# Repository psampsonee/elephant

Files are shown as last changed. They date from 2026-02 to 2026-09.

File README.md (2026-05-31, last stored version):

# Elephant

This project is intended to be a low-power audio player for a stuffed animal. The goal is to make a box that goes into a stuffed animal that takes up minimal space and lasts as long as possible on a single battery. The box should make an animal noise when its shaken, but only after some time has elapsed since the last time it has made a noise. The noise should be audible in a quiet room and should be immediately recognizable as a particular animal - in this case, an elephant. When the box has just been shaken, it will count - with very little power - a certain amount of time, then after that, wait to be shaken. Then, if you don't shake it, it should sit there, sipping very little power. When you do, it should make the animal noise within some amount of time (maybe a few fractions of a second).

## Power Budget / Battery Life

The board will have three main power states, corresponding to the three states of the state machine:

- Low-power
    - In this state, the STM32 is in standby mode. Everything but the backup domain - that is, the RTC and the backup registers - is powered off. Due to the quiescent currents of various devices during this state, it is expected that a little under 1 uA of current will draw from the main batteries.
- Buck Converter Off
    - The STM32 backup domain is powered only from its VBAT pin by the CR-2032 coin cell. Only the RTC and the backup registers are powered. This allows the STM32 to retain an accurate representation of the time. This will draw up to 2 uA from the CR-2032. However, testing will need to be done to verify this current consumption with the RTC in its particular configuration.
    - In this state, the buck converter becomes the predominate power sink for the main batteries, drawing 1 uA of current while shut down.
- Play Sound (highest power)
    - The microcontroller and DAC/amplifier (SSM2518) are both active, and the SSM2518 draws most of the current. This state will last for a few seconds, but contributes to a significant amount of the energy consumption of the main batteries. The LT-8640 will be supplying roughly 3.7W in this state and drawing 0.41A from the battery.

## State Machine

This firmware uses the Gang-of-Four State pattern: Elephant is the Context and each concrete state implements enter/toggle/exit. Each state is exposed via a singleton instance (no per-state heap allocations); any per-device data lives in the Elephant object. Interrupt service routines are kept tiny — they set flags or enqueue events — and the main loop/state handlers process those events and perform transitions, ensuring deterministic, non-blocking behavior. See notes in the README about concurrency (brief critical sections) and buffer sizing (samples vs bytes) (TODO).

The states in the state machine will correspond to each of the states mentioned in the **Power Budget / Battery Life** section above, with the following transition causes and tasks:

- Light Sleep
    - Upon waking up from standby, the firmware will detect why was reset (confirm entering standby), and why it woke (confirm RTC alarm) in main(). Once the STM32 is in this state, the STM32 will be in standby mode, corresponding to the "Low-power" power state.
    - Transitions to Deep Sleep when real time clock alarm fires. When the alarm fires, the STM32 briefly powers on completely to do the transition. During this transition, the microcontroller must save any data that needs to be retained (probably: last sound played (avoid repetition) and any state information needing to be retained) to spare backup registers, then pull the *GPIO_pwr_buck_off* pin low, triggering the 74AUP1G74 to clear, tying the LT8640 EN/UV pin low and causing it to power down.
- Deep Sleep
    - This state never sees a transition to another state in the code as the STM32 is completely powered off during it. Instead, the transition from this state occurs when the STM32 powers back on due to the LT8640 restoring power to the board. Corresponds to **Buck Converter Off**
    - "Transitions" to Play Sound when the tilt switch pulls the preload pin of the 74AUP1G74 low briefly, pulling Q high and turning the LT8640 back on.
- Play Sound
    - Upon powering on, the firmware will detect why was reset (POR), and why it woke (power restored) in main().  In this state, the STM32 will prepare the EEPROM for reading, then load data from the EEPROM in packets while playing a sound through the Audio object. Corresponds to the power state of the same name.
    - Transitions to Light Sleep when the Audio object completes playing a sound. During this transition, the STM32 sets an alarm 4 hours ahead of the current time to trigger it to wake up and transition into deep sleep.

## Choice of Components

### LT8640 Buck Converter

The LT8640 was chosen due to its high efficiency and ability to be turned off via the enable pin, which takes very little current to drive and allows the battery to be **practically** disconnected from the circuit (x nA is expected to leak while the LT8640 is turned off).

### STM32F401CCU Microcontroller

- Powerful enough to play intelligible audio
- Low-power options allow for RTC battery backup and external wakeups
- Nearly the same chip as on a "Black Pill" (For development)

### M95M04 EEPROM

- 4 Mbit is enough for several audio files (show calcs)
- Low Power
- 200 year data retention - not an SD card

### SSM2518 I2S DAC and amplifier

- Low quiescent current
- A one-chip solution to audio (maybe I dont need to say this in the final readme)
- Powerful enough to be heard at 2W per channel
-Very low noise

### LM66100 ideal diodes (power source OR-ing)

- Low quiescent (0.3uA) and leakage (max 600nA at operating temperature) currents
- Actively controlled PFET limits reverse-current to nanoamps. This is especially important for the coin cell to avoid damage, especially in high-temperature environments where a BAT54 could cause a failure in low-power mode.
- LM66100 ideal diodes were selected for power-source OR-ing due to their low quiescent current and low reverse leakage; reverse-current behavior into the coin cell is still being validated in simulation.

## Next Steps

## Risks and Unknowns

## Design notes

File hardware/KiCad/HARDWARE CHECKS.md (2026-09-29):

# Hardware Checks for Evaluation Board
## Schematic Checks
### 1. Power
- [x] Values of LT8640 passives match simulated LTSpice values.
- [ ] Power OR network topology verified against reference schematic
- [ ] Power OR network values verified via simulation or calculations
- [ ] Power OR back-current impedance to coin cell deemed acceptable
- [ ] Power OR decoupling caps are acceptable values
- [ ] Test points identified and verified
- [ ] 0-ohm bridges identified and verified
- [x] Inductor saturation - provide documented calculations verifying value.
- [x] Capacitor voltage and DC bias deratings keep capacitance values within specification
- [ ] Resistors are rated for anticipated peak and steady state currents based on LTSpice
- [ ] Regulator is capable of supplying expected steady state current without going into shutdown.
- [ ] Power network simulated against several conditions:
    - [x] Startup
    - [x] Steady State
    - [ ] Source-transition
    - [ ] Shutdown
- [ ] peak current and RMS current extracted from simulation and checked against component ratings as relevent
- [ ] Worst-case node voltages checked against component absolute-maximum ratings
- [ ] Thermal checks for devices
    Gather steady state (playback) and peak power + duration, and/or integrated energy
    - [ ] LT8640
    - [ ] LM66100 (x2)
    - [ ] Resistors
    compare against whatever thermal limits/guidance the datasheet actually provides
    flag anything that needs layout-dependent thermal verification
    require ~20% margin where a meaningful numeric limit exists

### 2. Tilt Switch Circuit
- [ ] Topology verified against test circuit
- [ ] Values verified against test circuit
- [ ] Test points identified and verified
- [ ] 0-ohm bridges identified and verified

### 3. MCU
- [ ] Topology verified against datasheet and/or known-good circuit
- [ ] VCAP1 value verified from datasheet
- [ ] LSE crystal impedance, capacitance, frequency verified against calcs from datasheet
- [ ] LSE network capacitor values verified against calcs from datasheet
- [ ] LSE crystal startup/load-cap tolerances
- [ ] HSE crystal frequency is an acceptable value for audio playback
- [ ] HSE crystal impedance, capacitance verified against calcs from datasheet
- [ ] HSE network capacitor values verified against calcs from datasheet
- [ ] HSE crystal startup/load-cap tolerances
- [ ] Has proximal AND distal decoupling caps at acceptable values
- [ ] Test points identified and verified
- [ ] 0-ohm bridges identified and verified
- [ ] NRST circuit
- [ ] Check NRST minimum pulse / pull-up / capacitor against datasheet recommendations
- [ ] BOOT pin state - defaults to allowing normal boot, but resettable.
- [ ] SWD pins
- [ ] VDDA/VSSA (analog circuit) - capacitors and reliability
- [ ] All VDD/VSS pins have connections
- [ ] Pin assignments (and functions) match a possible configuration in CubeMX
- [ ] Pin assignments are not absurd for board layout
    - [ ] Keep pins going to the same place close together
    - [ ] Decide beforehand where neighbors will be in relation to MCU and sanity-check pin locations for interconnections
- [ ] Verify every required power up sequencing requirement from datasheet
- [ ] Verify a recovery method exists if firmware disables/reconfigures SWD (i.e. reset or BOOT)
- [ ] Check that any peripherals will be successfully driven given I/O current limits.

### 4. EEPROM
- [ ] Pin functions backchecked against datasheet
- [ ] Pin connections backchecked against datasheet
- [ ] Has proximal AND distal decoupling caps at acceptable values
- [ ] Test points identified and verified
- [ ] 0-ohm bridges identified and verified
- [ ] **Default** states of pins do not:
    - [ ] Erase or change data
    - [ ] Put the EEPROM in an undefined state
    - [ ] Damage the EEPROM
    - [ ] Make the EEPROM consume unnecessary power
- [ ] Chosen EEPROM works with 3.3V SPI signals
- [ ] Maximum clock speed of the EEPROM exceeds intended STM32 SPI clock speed
- [ ] Check write-protect behavior during brownout/power collapse during writes when attached to debugger.
- [ ] Confirm SPI timing including CS setup/hold, not merely max SCK.

### 5. Audio Out
- [ ] Topology verified against datasheet and/or known-good circuit
- [ ] Pin functions backchecked against datasheet
- [ ] Pin connections backchecked against datasheet
- [ ] Checked capacitor values against available engineering calculations
- [ ] Has proximal AND distal decoupling caps at acceptable values
- [ ] Test points identified and verified
- [ ] 0-ohm bridges identified and verified
- [ ] Config pin reset states
- [ ] Address pin reset states
- [ ] Control pin reset states
- [ ] I2S logic levels 0V and 3.3V
- [ ] allowed MCLK/BCLK/LRCLK relationships versus what STM32 can actually generate
- [ ] speaker impedance/power against amplifier operating conditions
- [ ] output topology requires no accidental ground-referenced probing
- [ ] Output capacitor / filter requirements per datasheet
- [ ] Output network matches datasheet recommendation for short speaker leads
- [ ] Check maximum instantaneous supply current with intended speaker power
- [ ] Verify I2S word length / frame format can be supplied by STM32
- [ ] Check amplifier input and control pin states when MCU reset/unpowered conditions that can actually occur.

### 6. Debug Interface
- [ ] UART lines are all present
- [ ] UART lines have correct topology
- [ ] SWD lines are all present
- [ ] SWD lines have correct topology

### 7. Interface Checks
- [ ] Every IC supply pin checked for:
    - [ ] correct voltage
    - [ ] acceptable voltage range
    - [ ] adequate capacitor voltage rating
- [ ] Absolute-max / signal-level compatibility checked between devices
- [ ] Power-up/default states of important control pins verified
- [ ] MCU boot/reset configuration verified
- [ ] No required pull-ups/pull-downs omitted
- [ ] Connector pinouts independently backchecked
- [ ] Grounds and power-net names checked for accidental separation/connection
- [ ] ERC run and every warning reviewed rather than blindly waived
- [ ] Every external interface has a usable ground reference available for probing
- [ ] Programming/debug connector physically includes everything needed to recover a blank board
- [ ] Confirm no signal depends upon firmware driving it correctly during MCU reset
- [ ] Confirm unused pins are intentionally handled
- [ ] Confirm footprint/package selections against ordering part numbers
- [ ] Every connector is checked for mis-plug or reversed-plug consequences
- [ ] Every test point can be physically probed after assembly 
    (include this in board layout as well; tall components may make this hard)
- [ ] Verify PCB footprints:
    - [ ] Dimensions
    - [ ] Pin 1 orientation
    - [ ] Exposed pads
    - [ ] Courtyard
- [ ] Dead-MCU debug audit: identify every node that would need to be measured or controlled to diagnose a board where the MCU never runs; provide test access as appropriate.

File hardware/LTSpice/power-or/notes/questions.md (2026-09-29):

# Relevant Design Questions
1. What seams exist at source-transition and what are their worst-case conditions?
    A. What is the minimum VBackup voltage during handoff?
2. What are the worst-case leakage currents of the power-or network?
3. What are the worst-case transient and steady-state currents which could contribute to thermal load?
    - Particularly, worst-case capacitor charge inrush current.
4. What are the failure modes for this configuration?
    A. What happens if no coin cell is installed?
    B. Does a decaying buck output produce brownout or chatter?
    C. Any leakage through GPIOs when VDD=0?
    D. What happens when the backup node is shorted?
    E. What happens when the coin cell is reversed?
    F. What happens when the buck converter rail is shorted?
    G. What happens when the coin cell is at end of life?
    H. What does a replaced coin cell transient current look like when backup cap is discharged?
    I. What are the worst-case temperature conditions in regards to reverse leakage and FET behavior (hot AND cold)?
    J. What happens when one or both of the ideal diodes are shorted?
5. What is an acceptable VBackup capacitance?
    A. Start with 1uF and change if needed.
6. What happens during main power startup?
    A. Is voltage overshoot within an acceptable range?
    
# Simulations

- Handoff: Buck -> Coin cell
    - Model coin cell internal resistance
    - Check transient currents and backup cap discharge
    - Check diode states for chatter
    - Check backup voltage for brownout condition - Drives capacitance
- Handoff: Coin cell -> Buck
    - Check for voltage overshoot
    - Check for reverse transient current to coin cell
- Buck power off: reverse leakage to powered-off buck converter rail.
- Steady state, buck on: reverse leakage to coin cell
- Brand new coin cell transient: maximum current
- Failure conditions:
    - Backup battery reverse voltage
    - Backup node short
    - No backup battery
    - 2VDC buck voltage
    - Shorted ideal diode(s)
- Source crossover (Vbuck ~= Vcoin); buck sweeps slowly. Exposes partial diode conduction, source sharing, or chatter.

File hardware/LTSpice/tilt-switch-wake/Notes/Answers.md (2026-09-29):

## Questions

1. With worst-case maximum switch-closure duration, component values and parasitics, how does the RC node charge?
    - RC charging is effectively instantaneous relative to the minimum assumed switch-closure duration.
2. What maximum voltage does the RC node reach under the worst-case closure?

Measurements:
    - Maximum RC and EN node voltages
3. What is the minimum time that the EN node remains above threshold voltage (0.96V) during discharge?
4. How does GPIO interact with the tilt switch circuit?
    - Leakage current during discharge
    - backpowering
5. What is the worst-case leakage current from the tilt switch circuit while the buck converter is off?
    - With the tilt switch open, the always-on 3.3 V source has no intended DC path into the circuit. Remaining current is limited to physical open-switch leakage, expected to be negligible (nA-scale). No further simulation required.

## Simulations

1. Charging - Answers 1 and 2
2. Discharge / hold time - Answers 3

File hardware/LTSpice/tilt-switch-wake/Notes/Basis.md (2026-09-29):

# RC Time Constant Basis

## Experimentally derived variables

### STM32F401CU (Scope)

Minimum MCU supply voltage for GPIO assertion: 1.73V
Minimum time to assert GPIO: 5.69ms

### LT8640A-3.3

Output voltage: 3.3V
Time to reach minimum boot voltage (1.8V): 3.07ms (simulation result)

## Datasheet Variables:

LT8640 EN voltage: 1V
LT8640 EN hysteresis: 40mV

## Assumed / calculated variables

Minimum RC time above EN threshold: (5.69+3.07)*1.2=~10.5ms
Maximum RC charge voltage (90% of 90% of 3.3V): 2.67V
Discharging RC time constant (t1 = 10.5ms, V1 = 0.96V, V0 = 2.67V): -(t1/(ln(V1/V0)))=10.27ms
-> Given C=22nF, R=~600k

## Nominal charging and discharging characteristics

Based on this datasheet:
https://signalquest.com/wp-content/uploads/Tilt-and-Vibration-Sensor-SQ-SEN-200.pdf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

According to the vibration characteristic curve, assuming that either low-to-high or high-to-low counts as a transition, the estimated average closed-contact duration at \(D_{\max}\) is:

{2*D_max/(N_transitions|D_max)} ~= {2*0.65/1100} ~= 1.18ms

Since we don't have a particular switch in mind at this time, and it must be normally open for the wakeup circuit we have in mind to work, we will assume:

1.18 ms is approximately 12× 0.1 ms

and use 0.1ms as the assumed minimum available charging pulse, pending verification with real hardware.

## Crude impulse sensor

To later add functionality to determine roughly how much effort was put into a shake, an NMOS inverter circuit will be used in the final hardware. This will be neglected in LTspice tests.

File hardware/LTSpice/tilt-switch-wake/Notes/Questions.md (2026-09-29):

## Questions

1. With worst-case maximum switch-closure duration, component values and parasitics, how does the RC node charge?
2. What maximum voltage does the RC node reach under the worst-case closure?
Sweeps:
    - N/A
Measurements:
    - Maximum RC and EN node voltages
3. What is the minimum time that the EN node remains above threshold voltage (0.96V) during discharge?
4. How does GPIO interact with the tilt switch circuit?
    - Leakage current during discharge
    - backpowering
5. What is the worst-case leakage current from the tilt switch circuit while the buck converter is off?
    - With the tilt switch open, the always-on 3.3 V source has no intended DC path into the circuit. Remaining current is limited to physical open-switch leakage, expected to be negligible (nA-scale). No further simulation required.

## Simulations

1. Charging - Answers 1 and 2
2. Discharge / hold time - Answers 3

## Answers

1. RC charging is effectively instantaneous relative to the minimum assumed switch-closure duration.
2. 
    A. Maximum RC node voltage: 2.97V
    B. Maximum EN node voltage: 2.86V
3. Minimum time above threshold: 12.0ms
4. Open switch creates no meaningful off-state leakage path.
5. GPIO clamp/backfeed behavior is negligible in the modeled transient.

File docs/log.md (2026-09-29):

## 8/29/2026

Current State:

- Wrote schematic checklist for Rev A board

Next steps:

- Clean up LT-8640 LTSpice model and begin verifying component ratings in the power section, adjusting idealized assumptions.
- Establish one canonical cleaned-up LT-8640 baseline before beginning simulations. Record the source of each value (i.e. datasheet) for future reference.
    - Voltage-derated input/output capacitor values
    - Capacitor ESR, esp. on output cap.
    - Inductor DCR
    - Realistic battery voltage and source resistances
    - One parameterized load (parameterized current source)
- Each question gets a separate simulation file.
    - Startup at worst-case load (verify ~3.3V)
    - Load transient from idle to playback
    - Battery corner: Vbat_min and worst-case source resistances
    - Component stress: Peak/RMS currents and voltages
    - Shutdown: Check behavior when EN drops below 1 V
    - Source / OR behavior: Backfeed/source transitions (multiple tests)
        - Backfeed steady state
        - Transition transients
        
## 9/1/2026

Current State:

- Cleaned up LTSpice directory structure
- Began parameterizing LTSpice buck convertor model

Next Steps:

- Construct effective/test values from nominal values × derating/tolerance factors
- Apply those parameters throughout the LTspice model
- Populate nominal values, tolerances, derating factors, ESR/DCR, etc. from datasheets/design documentation; cite sources in bib.md

9/5/2026

Current State:

- Set up Buck Convertor LTSpice workspace and documentation files.
- Began gathering parameters and SPICE models from datasheets

Next Steps:

- Finish gathering parameters from datasheets, putting documentation in .inc/bib.md/bib.ods as needed
- Prepare test conditions.

9/6/2026

Current State:

- Gathered component parameters and models from vendors with documentation
- Ran initial bringup simulation

Next Steps:

- Sweep Distal Vin/Vout capacitors for anticipated current dips
- Test battery corners
- Test various loads
- Test startup under load
- Test shutdown

9/7/2026

Current State:

- Completed baseline simulation
- Produced C_IN_DISTAL sizing simulation during steady state
- For steady state, a capacitance of 47uF captures most of the improvement in VIN ripple and VIN minimum, with diminishing returns above that.

Next Steps:

- C_IN_DISTAL startup simulation and tests
- Battery corner tests.

9/12/2026

Current State

Re-defined test conditions - input bulk capacitor
Determined component measurements
Ran all three conditions and revised the above two based on results

Next Steps

Revise steady state power for 30% rather than 20% max playback power
Write load switching measurements in LTSpice

9/13/2026

All VIN-cap tests rerun with consistent battery states and recovery metrics. Next: tabulate results only—do not change tests unless the table exposes a problem.

9/19/2026

Current State

Verified VIN bulk capacitor and VOUT bulk capacitor selection.

Next Steps

Buck converter design verification checkoffs from existing checklist
Power-or circuit simulation:
    - Design criteria
    - Test questions
    - Corners / state transitions
    
9/20/2026

Current State

Checked Buck KiCad against LTSpice: topology and nominal values.
Added evaluation features to KiCad schematic.
Organized LTSpice folders.

Next Steps

Verify buck enable behavior.
    - Disable threshold, falling EN
    - Enable thresh, rising EN
    - Shutdown decay (Time from 3.3V to 1.8V) when EN pulled low quickly. Should be around (60uC per amp)s.
Investigate passive wake circuit with MCU self-hold.
    - determine required EN hold time from the results above
    - measure/estimate MCU boot-to-GPIO-assert time
    - see whether RC + diode can guarantee that at worst-case VBackup
    - check standby leakage
Power-or verifications

9/21/2026

Results:
- Time to decay when disabled: 863us.
- Time to reach minimum boot voltage (1.8V): 3.07ms

Next steps

Investigate passive wake circuit with MCU self-hold and nominal EN voltage thresholds.

9/22/2026

Current State
- Captured time from 1.73V (experimentally verified minimum GPIO voltage) applied to input rail to GPIO assert on STM32F401 in gpio-assert-test.
- Result:5.69ms
- Negligible observed run-to-run variation over several trials.
- Target time for RC filter to remain above 0.96V (LT8640 EN threshold): (5.69ms+0.00307ms)*1.2=~6.84ms (20% safety factor)

Next steps:
- Determine RC time constant to meet the requirement of decaying from 2.67V to 0.96V in 6.84ms
- Determine minimum viable tilt switch closed time (Let's say the RC must charge to at least 90% of 2.97V (which is 90% of 3.3V))
- Simulate using the selected impulse and RC values (as well as parasitics/nonideals) to verify.

9/26/2026

Current State
- Plans for impulse sensing via NMOS inverter
- Wrote up RC basis
- Simulated to verify answers to tilt switch circuit questions
    - EN hold time: 9.19 ms minimum vs. 6.84 ms required
    - RC charging effectively instantaneous relative to 100 µs assumed switch pulse
    - No meaningful GPIO backfeed/leakage observed

Next steps
- Pick parts
- Power OR ckt

9/27/2026

Current State
- Copied tilt switch wake circuit into KiCad
- Determined that a series resistor to the RC node of the wake circuit would suffice for switch sensing.
- Designed questions and tests for power-or circuit

Next Steps
- Perform Power-Or tests
- Complete power checklist
- Move on to MCU checks
- there was a magnitude error in the RC calculation. Fix it.

9/29/2026

Current State
- Recalculated RC values, updated docs.
- Re-simulated tilt switch circuit with datasheet component values, found that chosen parts exceed the new requirements.
- Produced baseline power-or simulation with old LM66100 model

Next steps
- Create and execute power handoff tests
- Create and execute source crossover test
- Create and execute reverse leakage tests (buck off/buck on)
- Create and execute Cbackup sweep test (variant of buck->coin cell test)
- Create and execute the four fault conditions highlighted (backup node short/diodes shorted/coin cell flipped/no coin cell)
- Complete power checklist

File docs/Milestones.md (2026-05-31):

Milestones

Initial Prototype
- Play sound
- Read/write EEPROM
- Play sound while using EEPROM
- RTC alarms are implemented
- State machine works properly
- Sleep/Shutdown implemented and the prototype works functionally
- Prototype performs full cycle:
    sleep → wake → play → sleep
- startup and pin assertion time recorded (See next section)

Power (SPICE)
- Buck converter implemented, known working (as designed on schematic)
- Power OR working
- tilt switch/EN trigger working (~100ms enabled after tilt event, verified during prototyping)

Firmware (It largely exists, but big chunks dont or need to be rewritten)
Firmware architecture reviewed
Critical modules reviewed (state machine, audio, EEPROM)
Wake source correctly identified after reset
Unit tests implemented
Unit tests passing

Board readiness
Schematic reviewed
Power paths verified
Buck converter layout reviewed
Decoupling verified
Test points/0-ohm ties identified and added
Instrumentation points added (current measurement):
    shunt resistor or test pads for current
    buck enable signal probe
    VBAT probe
ERC/DRC

Bring-up
Board powers up, no overheating
3.3V rail stable
MCU programmable
Amplifier powers up, works
Audio playback verified

Verification
(board approaches simulation results for power consumption)
Low-power current measured
Buck-off current measured
Playing current measured and adjusted to balance audibility and battery life
Wake latency measured

Reliability
Several shake events tested
Sleep/wake cycles tested
failure modes tested: one battery or the other removed, tilt switch stuck, one thing or another won't turn on or off
Go to university and see if i can get time on a thermal camera, verify nothing heats more than necessary
Long-duration idle test (24–72 hours)

Most likely to stall: 
Playing a sound
Wake / power-gating logic
Board power-up

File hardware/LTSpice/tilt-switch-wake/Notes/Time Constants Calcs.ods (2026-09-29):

 | R | C | Tau | Initial Voltage | t1 | V|t1 | Threshold voltage | Time-to-threshold
Charging (Nom) | 10 | 2.20E-08 | 0.00000022 | 2.97 | 1.00E-04 | 2.97 | 1.04 | 9.48292289775191E-08
Discharging (Nom) | 5.00E+05 | 2.20E-08 | 0.011 | 2.97 | 1.05E-02 | 1.14216500573209 | 0.96 | 0.0124232234206835
Charging (Worst Case) | 10 | 0.0000000242 | 0.000000242 | 2.31 | 1.00E-04 | 2.31 | 1.04 | 1.44771811023295E-07
Discharging (Worst Case)

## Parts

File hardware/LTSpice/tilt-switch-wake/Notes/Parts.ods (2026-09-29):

Reference | LTSpice Param | Description | Manufacturer | Part No. | Source | Parameters Used | Notes
 |  | Charging Capacitor | YAGEO | CC0805KRX7R7BB223 | https://yageogroup.com/download/specsheet/CC0805KRX7R7BB223 | DC Bias (3.3% at ~3V), Tolerance
 |  | Discharge Resistor | YAGEO | RC0805FR-07590KL | https://yageogroup.com/content/datasheet/asset/file/PYU-RC_GROUP_51_ROHS_L | Resistance, Power
 |  | Diodes | SMC | BAT54 | https://www.smc-diodes.com/propdf/BAT54(A)(C)(S)%20N0123%20REV.D.pdf | LTSpice Model for part number
 |  | GPIO Series Resistor | YAGEO | RC0603FR-0710KL | https://yageogroup.com/content/datasheet/asset/file/PYU-RC_GROUP_51_ROHS_L | N/A

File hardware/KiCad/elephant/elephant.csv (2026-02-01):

# | Reference | Qty | Value | Footprint | DNP
1 | BT1 | 1 | 9v Battery | Connector_JST:JST_PH_B2B-PH-K_1x02_P2.00mm_Vertical
2 | BT2 | 1 | Coin Cell | Battery:BatteryHolder_Keystone_1057_1x2032
3 | C1, C2, C4, C14 | 4 | 1uF | Capacitor_SMD:C_0603_1608Metric
4 | C3 | 1 | 100u | Library:Capacitor SMD 2917 (7343 Metric)
5 | C5, C6, C7, C11 | 4 | 470pF | Capacitor_SMD:C_0603_1608Metric
6 | C8, C9 | 2 | 2pF | Capacitor_SMD:C_0603_1608Metric
7 | C10 | 1 | 4.7uF,<1Ω | Capacitor_SMD:C_0603_1608Metric
8 | C12, C13 | 2 | 4pF | Capacitor_SMD:C_0603_1608Metric
9 | C15 | 1 | 10nF | Capacitor_SMD:C_0603_1608Metric
10 | C16, C18 | 2 | 100nF | Capacitor_SMD:C_0603_1608Metric
11 | C17 | 1 | 4.7uF | Capacitor_SMD:C_0603_1608Metric
12 | D3 | 1 | LED | LED_SMD:LED_0603_1608Metric
13 | FB1, FB2, FB3, FB4 | 4 | FerriteBead_Small | Inductor_SMD:L_0402_1005Metric
14 | H1, H2, H3, H4 | 4 | MountingHole | MountingHole:MountingHole_2.7mm_M2.5
15 | J1 | 1 | Conn_01x04_Pin | Connector_JST:JST_PH_B4B-PH-K_1x04_P2.00mm_Vertical
16 | J2 | 1 | Conn_01x05_Pin | Connector_JST:JST_PH_B5B-PH-K_1x05_P2.00mm_Vertical
17 | L1 | 1 | 2.2uH | Inductor_SMD:L_Bourns-SRN8040_8x8.15mm
18 | LS1, LS2 | 2 | Speaker | Connector_JST:JST_PH_B2B-PH-K_1x02_P2.00mm_Vertical
19 | R1 | 1 | 10k | Resistor_SMD:R_0603_1608Metric
20 | R2 | 1 | 500Ω | paul:TC42 – 2 mm SMD Trimpot - Bournes
21 | R4 | 1 | 2.4kΩ | Resistor_SMD:R_0603_1608Metric
22 | R7 | 1 | 330 Ω | Resistor_SMD:R_0603_1608Metric
23 | R8 | 1 | 17.8k | Resistor_SMD:R_0603_1608Metric
24 | SW1 | 1 | SW_TILT | Connector_PinHeader_2.54mm:PinHeader_1x02_P2.54mm_Vertical
25 | TP1 | 1 | 3v3 | TestPoint:TestPoint_Pad_D1.0mm
26 | TP2 | 1 | GND | TestPoint:TestPoint_Pad_D1.0mm
27 | U1 | 1 | LT8640 | paul:LT8640
28 | U3 | 1 | SSM2518 | Package_DFN_QFN:QFN-20-1EP_4x4mm_P0.5mm_EP2.5x2.5mm
29 | U4 | 1 | M95M04 | Package_SO:TSSOP-8_4.4x3mm_P0.65mm
30 | U5 | 1 | STM32F401CCUx | Package_DFN_QFN:QFN-48-1EP_7x7mm_P0.5mm_EP5.6x5.6mm
31 | Y1 | 1 | 32.768kHz, 6pF, 50kΩ | Crystal:Crystal_SMD_Abracon_ABS25-4Pin_8.0x3.8mm
32 | Y2 | 1 | 16MHz, 7pF, 60Ω | Crystal:Crystal_SMD_3225-4Pin_3.2x2.5mm

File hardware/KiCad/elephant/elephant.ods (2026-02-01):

# | Reference | Qty | Value | Footprint | Digikey Part
1 | BT1 | 1 | 9v Battery | Connector_JST:JST_PH_B2B-PH-K_1x02_P2.00mm_Vertical | https://www.digikey.com/en/products/detail/keystone-electronics/232/303804
2 | BT2 | 1 | Coin Cell | Battery:BatteryHolder_Keystone_1057_1x2032 | https://www.digikey.com/en/products/detail/keystone-electronics/1057TR/4692903
3 | C1, C2, C4, C14 | 4 | 1uF | Capacitor_SMD:C_0603_1608Metric | https://www.digikey.com/en/products/detail/samsung-electro-mechanics/CL10A105KA8NNNC/3886760
4 | C3 | 1 | 100u | Library:Capacitor SMD 2917 (7343 Metric) | https://www.digikey.com/en/products/detail/kyocera-avx/TCJY107M016R0050/5001463
5 | C5, C6, C7, C11 | 4 | 470pF | Capacitor_SMD:C_0201_0603Metric | https://www.digikey.com/en/products/detail/murata-electronics/GRM033R71C471KA01D/2543516
6 | C8, C9 | 2 | 2pF | Capacitor_SMD:C_0201_0603Metric | https://www.digikey.com/en/products/detail/murata-electronics/GRM0335C1H2R0BA01D/4358709
7 | C10 | 1 | 4.7uF,<1Ω | paul:1411 (3528 Metric) | https://www.digikey.com/en/products/detail/vishay-sprague/TR3B475K035C0700/2259924
8 | C12, C13 | 2 | 4pF | Capacitor_SMD:C_0201_0603Metric | https://www.digikey.com/en/products/detail/murata-electronics/GRM0335C1E4R0CA01D/4358231
9 | C15 | 1 | 10nF | Capacitor_SMD:C_0201_0603Metric | https://www.digikey.com/en/products/detail/murata-electronics/GRM033R71A103KA01D/702460
10 | C16, C18 | 2 | 100nF | Capacitor_SMD:C_0201_0603Metric | https://www.digikey.com/en/products/detail/murata-electronics/GRM033R61A104ME15D/2175191
11 | C17 | 1 | 4.7uF | Capacitor_SMD:C_0603_1608Metric | https://www.digikey.com/en/products/detail/samsung-electro-mechanics/CL10A475KP8NNNC/3886702
12 | D3 | 1 | LED | LED_SMD:LED_0603_1608Metric | https://www.digikey.com/en/products/detail/creeled-inc/XQEGRN-H2-0000-000000B01/5423124
13 | FB1, FB2, FB3, FB4 | 4 | FerriteBead_Small | Inductor_SMD:L_0402_1005Metric | https://www.digikey.com/en/products/detail/laird-signal-integrity-products/MI0402K121R-10/4765745
14 | H1, H2, H3, H4 | 4 | MountingHole | MountingHole:MountingHole_2.7mm_M2.5 | N/A
15 | J1 | 1 | Conn_01x04_Pin | Connector_JST:JST_PH_B4B-PH-K_1x04_P2.00mm_Vertical | N/A
16 | J2 | 1 | Conn_01x05_Pin | Connector_JST:JST_PH_B5B-PH-K_1x05_P2.00mm_Vertical | N/A
17 | L1 | 1 | 2.2uH | Inductor_SMD:L_Bourns-SRN8040_8x8.15mm | https://www.digikey.com/en/products/detail/bourns-inc/SRN8040-2R2Y/2756130
18 | LS1, LS2 | 2 | Speaker | Connector_JST:JST_PH_B2B-PH-K_1x02_P2.00mm_Vertical | https://www.digikey.com/en/products/detail/pui-audio-inc/AS04008CO-WR-R/1745536
19 | R1 | 1 | 10k | Resistor_SMD:R_0603_1608Metric | https://www.digikey.com/en/products/detail/yageo/RC0603FR-0710KL/726880
20 | R2 | 1 | 500Ω | paul:TC42 – 2 mm SMD Trimpot - Bournes | https://www.digikey.com/en/products/detail/bourns-inc/TC42X-2-501E/3722204
21 | R4 | 1 | 2.4kΩ | Resistor_SMD:R_0603_1608Metric | https://www.digikey.com/en/products/detail/yageo/RC0603FR-072K4L/727023
22 | R7 | 1 | 330 Ω | Resistor_SMD:R_0603_1608Metric | https://www.digikey.com/en/products/detail/yageo/RC0603JR-07330RL/726769
23 | R8 | 1 | 17.8k | Resistor_SMD:R_0603_1608Metric | https://www.digikey.com/en/products/detail/yageo/RC0603FR-0717K8L/726983
24 | SW1 | 1 | SW_TILT | Connector_PinHeader_2.54mm:PinHeader_1x02_P2.54mm_Vertical | N/A
25 | TP1 | 1 | 3v3 | TestPoint:TestPoint_Pad_D1.0mm | N/A
26 | TP2 | 1 | GND | TestPoint:TestPoint_Pad_D1.0mm | N/A
27 | U1 | 1 | LT8640 | paul:LT8640 | https://www.digikey.com/en/products/detail/analog-devices-inc/LT8640AJUDCM-3-3-PBF/17952220
28 | U3 | 1 | SSM2518 | Package_DFN_QFN:QFN-20-1EP_4x4mm_P0.5mm_EP2.5x2.5mm | https://www.digikey.com/en/products/detail/analog-devices-inc/SSM2518CPZ-R7/3043350
29 | U4 | 1 | M95M04 | Package_SO:TSSOP-8_4.4x3mm_P0.65mm | https://www.digikey.com/en/products/detail/stmicroelectronics/M95M04-DRDW6TP/11482497
30 | U5 | 1 | STM32F401CCUx | Package_DFN_QFN:QFN-48-1EP_7x7mm_P0.5mm_EP5.6x5.6mm | https://www.digikey.com/en/products/detail/stmicroelectronics/STM32F401CCU6/4755971
31 | Y1 | 1 | 32.768kHz, 6pF, 50kΩ | Crystal:Crystal_SMD_Abracon_ABS25-4Pin_8.0x3.8mm | https://www.digikey.com/en/products/detail/ecs-inc/ECS-327-6-17X-C-TR/5875555
32 | Y2 | 1 | 16MHz, 7pF, 60Ω | Crystal:Crystal_SMD_3225-4Pin_3.2x2.5mm | https://www.digikey.com/en/products/detail/ecs-inc/ECS-160-7-33B2-CKM-TR3/18108759

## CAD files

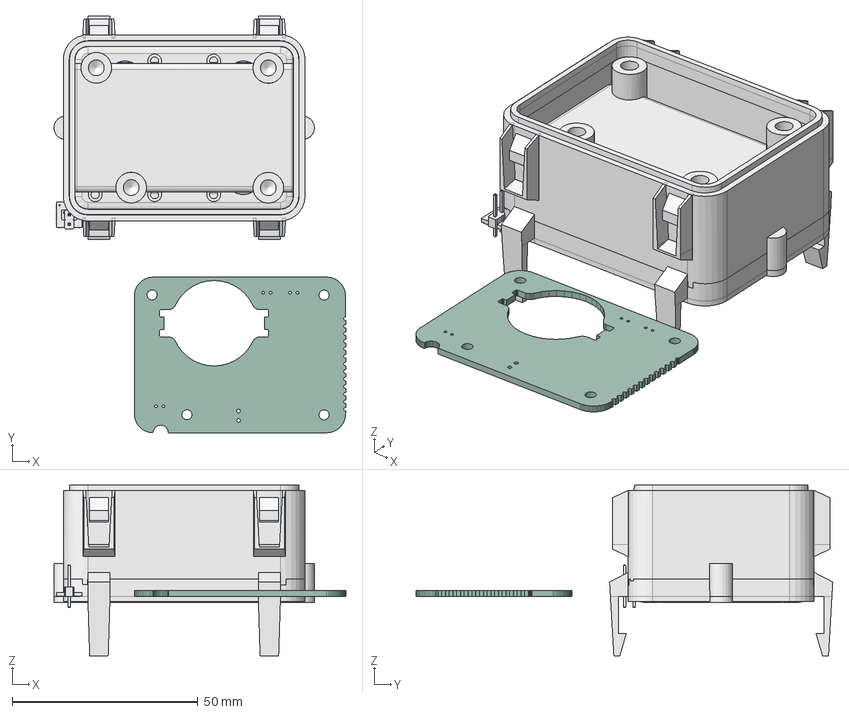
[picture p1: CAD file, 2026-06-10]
hardware/FreeCad/Enclosure.FCStd
78.6 x 112.2 x 46.0 mm
batterydoor
C_0201_0603Metric
C_0201_0603Metric002
C_0201_0603Metric004
QFN-20-1EP_4x4mm_Pitch0.5mm
L_0402_1005Metric
C_0603_1608Metric
L_0402_1005Metric002
C_0603_1608Metric002
C_0201_0603Metric006
PinHeader_1x02_P254mm_Vertical
R_0603_1608Metric
C_0603_1608Metric004
TSSOP_8_44x3mm_P065mm
C_0201_0603Metric008
Crystal_SMD_3225-4Pin_3.2x2.5mm
QFN_48_1EP_7x7mm_P05mm_EP56x56mm
C_0201_0603Metric010
C_0201_0603Metric012
C_0201_0603Metric014
C_0201_0603Metric016
LED_0603_1608Metric
R_0603_1608Metric002
R_0603_1608Metric004
C_0603_1608Metric006
R_0603_1608Metric006
C_0201_0603Metric018
C_0201_0603Metric020
L_0402_1005Metric004
C_0603_1608Metric008
L_0402_1005Metric006

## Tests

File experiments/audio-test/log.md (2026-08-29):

6/27/2026

Current state:
- Narrative/invariants are still confusing.
- SampleSpooler is basically unit-testable and mostly settled.
- AudioPlayer needs a clearer state machine boundary.

Next step:
- Write the smallest AudioPlayer unit test for start(): valid start request moves Idle -> Prepare or Error on invalid arguments.

6/29/2026

Next step:
Turn SampleSpooler functions into booleans for error handling
Write code for AudioPlayer servicePrepare & servicePlayback
Rewrite markRefilled to automatically fill partial buffers with silence

7/3/2026

Current state:
- Added a silence-filling feature for partial buffers in spooler
- Fake sink and storage devices are unit tested and work
- Began adding basic behavior code to servicePrepare()
- Added refillOneBuffer to AudioPlayer.
- Added samplesRemaining_ to AudioPlayer as a way to track samples read from the storage device.

Next steps:
- Make refillOneBuffer functional by adding code to derive samplesRemainingToRead_
- Make one unit test to test refillOneBuffer.
- Make unit tests to test AudioPlayer state machine.

7/4/2026

Current state:
- Fake sink extended to include initialization steps
- AudioPlayer::refillOneBuffer(uint8_t index) defined and written
- Added samplesRemainingToRead_ to track the number of samples to read left from storage for the given clip.
- AudioPlayer servicePrepare code outline written
- Began creating a test harness for the AudioPlayer

Next steps:
- Begin initialization tests for AudioPlayer

7/5/2026

Current state:
- AudioPlayer test code compiles without error
- Basic AudioPlayer initialization tests run without error
- Created test handles struct to easily initialize fake sink, fake storage, and AudioPlayer.

Next steps:
- Write tests for playback state
- Write tests for error states
- Fill in code for servicePlayback

7/7/2026

Current state:
- Wrote servicePlayback code

Next steps:
- Write tests for playback state
- Write tests for error states

7/8/2026

Current state:
- Listed several successful-path unit tests to write in test_audio_player.cpp

Next steps:
- Write successful-path unit tests and get them to pass
- List failure unit tests

7/9/2026

Current state:
- Wrote and successfully ran several happy-path unit tests in test_audio_player.cpp:
    - test_start_while_playing_stops_current_playback_first()
    - test_start_from_finished_enters_prepare_without_stopping()
    - test_service_playback_consumes_samples()
    - test_samples_played_equals_samples_written()
    - test_successful_playback_enters_finished()
    
Next steps:
- Practical and underrun unit tests
- Error-path tests
- Begin tests on real hardware

7/12/2026

Current state:
- Wrote unit test showing that storage sectors are written to the spooler successfully.

Next steps:
- Error-path tests
- Begin tests on real hardware

7/13/2026

Current state:
- Added player read error test and functionality
- Added storage read status functionality
- Added player underrun test (which fails)

Next steps:
- Get the underrun test to pass.

7/14/2026

Current state:
- Wired amplifier on breadboard
- Configured STM32 for 25MHz clock
- Set up TIM4 for 200kHz PWM
- Confirmed 200kHz square wave with USB scope

Next steps:
- Make underrun test pass—trace expected transition and identify where the fake readiness behavior diverges.
- solder pins to speaker
- generate 500Hz sine wave table at 44.1kHz sample rate
- Use a timer interrupt at 44.1 kHz to update TIM4 CCR to the next sine wave sample (+- 10).

7/15/2026

Current State:
- AudioPlayer happy path, error handling, and underrun behavior are tested and work in fake environment.

Next Steps:
- solder pins to speaker
- generate 500Hz sine wave table at 44.1kHz sample rate
- Use a timer interrupt at 44.1 kHz to update TIM4 CCR to the next sine wave sample (+- 10).

7/16/2026

Current state:
- Made a working LM386 amplifier circuit on a breadboard.
- Used STM32 PWM and timers to play a sine wave on the amplifier
- The cat screwed it up.

Next steps:
- Fix the circuit and make it play sound again
- Write PwmAudioSink to interface the PWM audio with the AudioPlayer
- Use hal_callbacks.cpp in App/Src folder to hold a callback for the timer interrupt which updates the PWM sample.

7/17/2026

Current state:
- Created hal_callbacks.cpp to handle all interrupt callbacks that the program may have
- Filled out pwm_audio_sink.h sufficiently to begin implementation
- Created empty function implementations in pwm_audio_sink.cpp

Next steps:
- Implement prepare, start, and interrupt / sample functionality.
- Mind error handling and return false when invariants are violated.

7/20/2026

Current State:
- PwmAudioSink is functional enough to create arbitrary waveforms with expected distortion.
- Tested on Analog Discovery 2.

Next steps:
- Implement PwmAudioSink interrupt failure detection (i.e. timeout / watchdog)
- Reduce amplifier gain with a pot.
- Complete sd_card storage_device implementation
- Test sd_card storage_device implementation
- Test AudioPlayer with SDcard -> PwmAudioSink pipeline in place

7/25/2026

Current State:
- Created 48000 Hz Signed 16-bit PCM test file with Audacity.
- Tested AudioPlayer functionality with SD card storage and PWM audio sink.
- Spotted shadowed variable in AudioSink (isSampleNeeded_).
- AudioPlayer can successfully play an audio clip from storage on a functioning audio sink.

Next Steps:
- Design SSM2518 / EEPROM interface board.
- Configure and verify the SSM2518 over I2C.
- Produce a simple I2S tone.
- Stream a PCM buffer through I2S DMA.
- Connect that sink to the existing AudioPlayer.
- Implement ADPCM compression to optimize for limited EEPROM capacity.

~7/31/2026

Current State:
- Wrote ADPCM codec

Next Steps:
- Testing and integration of ADPCM codec.

8/8/2026

Current State:
- Successfully tested ADPCM codec on PC
- Wrote headers for SampleSource, StorageSampleSource, and PCM/ADPCM sources to convert data into samples
- Refactored AudioPlayer to use SampleSource instead of StorageDevice.
    - Consistently use size_t instead of uint32_t for variable indexes / counts
    - Refactored refillOneBuffer per the SampleSource contract
- Put some code from audio_player.cpp into PCMSampleSource (bookkeeping & some code from refillOneBuffer)

Next Steps:
- Write PCMSampleSource implementation
- Test PCMSampleSource implementation

8/13/2026

Current State:
- Wrote PCMSampleSource.
- Need to assert invariants after the fact

Next Steps:
- Write down PCMSampleSource invariants (esp. getSamples)
- Test PCMSampleSource

8/24/2026

Current State:
- PCMSampleSource is tested
- In process of tesing AudioPlayer with new source_ interface

Next Steps:
- The first sector of storage is being read twice, once by source_.start and once by source_.getSamples. It seems to be a bookkeeping problem at start but I have not traced it through yet.
- Underruns are not being tracked by AudioPlayer at this time.
- Create helper function in the source to handle storage read transactions.

8/24/2026 (B)

Current State:
- Created a dedicated function fillWorkspace() to handle storage read transactions in PCMSampleSource.
- Narrowed underrun problem to a hypothesis: sourceReadPosition_final is invalid.
- Leaving for a week.

Next Steps:
- Test hypothesis
- Make that variable valid.
- Create dedicated tests:
    - Show that blocks are not repeated under normal conditions
    - Show that the contents of each sample out matches the value of the expected sample in.

8/26/2026

Current State:

- Fixed underrun bug: buffers are not marked for refill if the number of samples to be written is 0.
- Added above two tests to AudioPlayer test code

Next Steps:

- Write ADPCM Sample Source.

8/27/2026

Session 1:

Current State:

- Distinguished storage "sectors" from ADPCM "frames" (previously, both were "blocks"
- ADPCMSampleSource now has a compressedBuffer containing compressed ADPCM data
- Decoupled getSamples from sectors.
    - Must take charge of clipSamplesToDestination_
    - Uses workspaceSampleCount_ to determine the number of samples currently in workspace.
- fillWorkspace will orchestrate this process:
    - Determine if compressedBuffer is used up and call fillCompressedBuffer if so
    - Determine if the current ADPCM frame is exhausted and decode the next ADPCM frame header and update the sample state with it if so (startADPCMFrame)
    - Decode enough PCM frames to fit into workspace_ (currently 512) using looped calls of getNextDecodedSample
    - Report the number of valid samples that workspace_ is currently holding in workspaceSampleCount_.

Next steps:
- Flesh out fillWorkspace invariants and functionality
- Write startADPCMFrame and getNextDecodedSample from test code.

Session 2:

Current State:

- Implemented ADPCMSampleSource and added several helper functions.

Next Steps

- Test ADPCMSampleSource in a similar way PCMSampleSource was tested.
    - With FakeStorageDevice
    - With AudioPlayer and FakeStorageDevice
    - Run the fake storage filler algorithm through an ADPCM codec and check against exact values for the above tests.
    - Use sample error checking that allows for some amount of error inherent to ADPCM to check against PCMSampleSource using actual audio.
- Lay out Audio test board.

8/28/2026

Current State:

- Created a foundation for test code for ADPCMSampleSource.
- Began initial tests for ADPCMSampleSource and fixed a state error where workspace_ was not being filled in start function.
- Created unit tests for ADPCMSampleSource. Uniquely:
    - Created ADPCMSampleSource unit tests based on PCMSampleSource tests.
    - Created a test that checks each ADPCMSampleSource output against pre-decoded PCM values, rather than checking buffer boundaries directly.
- Got AudioPlayer unit tests to work with ADPCMSampleSource with minimal modification (aside from removing the assumption of data in == samples out)

Next Steps:

- Lay out audio test board
- component procurement as necessary

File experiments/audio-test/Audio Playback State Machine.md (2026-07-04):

# Audio Playback State Machine

## Narrative

This system sits idle until the main program requests playback from a particular sample at an index. Then, it initializes by preparing the SD card for read access, preparing spooler buffers to be filled, and preparing the PWM output for playback. It will play back until it reaches the number of samples that the main program said was the length of the sample. Then, it will go back to the idle state. If SD card transactions are slow or stop and buffers aren't getting full during playback, the system will enter the Underrun state. In this state, it will attempt to refill the buffers until a certain amount of time has passed, then enter the Error state. Impossible conditions, such as variables outside of their maximum values, lead to the Error state.

## Invariants

Global Invariants:
    playBuf_ < NumBuffers
    playPos_ < SamplesPerBuffer
    samplesLeft_ >= 0
    state_ is a valid State value
    current buffer index is never used unless it is in range

Idle:
    No playback is active
    All errors are cleared
    A valid play command may transition to Prepare

Prepare:
    Has a valid playback request
    Has a valid start sector
    Has a valid sample length
    Buffers are treated as invalid until filled
    Exit to Playing only after required buffers are valid

Playback:
    Current playback buffer must be valid
    samplesLeft_ > 0
    playPos_ < number of valid samples in current buffer
    There must be a valid file length for the current file listed
    Empty buffers are marked for refill

Underrun:
    The next buffer to be played is marked for refill
    No invalid data is sent to PWM
    Exit to playing when the next 2 buffers to be played are valid

Error:
    Audio output is in a safe silent state
    No further SD/PWM assumptions are trusted

## The State Machine

* Idle
    (Do nothing)
    
    * play command -> Prepare

* Prepare
    acquire SD access
    seek to sample start sector
    prime first playback buffers
    configure PWM/timer
    start playback timer only after buffers are valid
    Prime spooler
    Setup pin for PWM output
    
    * success -> Playback
    * failure -> Error

* Playback
    Take a sample from Spooler and put it onto PWM
    Fill any empty buffers with samples from SD
    Pad extra space after current file with silence
    Fault if invariants are violated
    Complete if samplesPlayed >= totalSamples
    
    * complete -> Finished (silence / stop PWM, clear playback)
    * buffer unexpectedly empty -> Underrun
    * fault -> Error **
    * stop command -> Idle

* Underrun
    Put PWM in "safe" state (hold last sample or silence)
    SD card read -> buffer
    If fails, wait x ms and try again.
    After y ms, timeout.
    
    * data arrives -> Playback
    * timeout -> Error

* Finished
    Silence on playback
    
    * reset -> Idle
    
* Error
    Notify main program and wait for clear.

    cleared/reset -> Idle

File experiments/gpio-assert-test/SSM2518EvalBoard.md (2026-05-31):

# SSM2518 Audio Evaluation Board

Goal: make a small test PCB that proves the Elephant audio chain:
STM32/Black Pill → I2S + I2C → SSM2518 → speaker.

[ ] Add I2S header: MCLK, BCLK, LRCLK, SDATA, GND
[ ] Add I2C header: SCL, SDA, GND, 3V3
[ ] Add logic analyzer test points for all I2S lines
[ ] Add test points for 3V3, GND, amp enable/config pins
[ ] Add speaker screw terminal or JST connector
[ ] Add jumpers/solder bridges for address/config options
[ ] Add optional shutdown/enable control pin header
[ ] Include M95M04 EEPROM on audio test PCB - 1 hr
[ ] Add SPI test points/header for EEPROM: CS, SCK, MISO, MOSI, GND - 0.5 hr
[ ] Write/restore EEPROM loading script or firmware path - 2 hr
[ ] Verify EEPROM read speed is enough for audio streaming - 2 hr
[ ] Test EEPROM read while I2S playback is active - 3 hr
[ ] Confirm buffering strategy: samples vs bytes, packet size, underrun behavior - 2 hr
[ ] Play real elephant audio from EEPROM through SSM2518 - 2 hr

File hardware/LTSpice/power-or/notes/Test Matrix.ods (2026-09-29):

Test | Operating condition | Stimulus | Measurements | Worst-case corners | Acceptance criteria
Buck → coin-cell handoff | Buck initially supplies VBackup; coin cell installed | Ramp/decay Vbuck from nominal to 0 using expected shutdown waveform | Minimum VBackup; coin-cell current; backup-cap current; handoff duration; ideal-diode states | Minimum coin-cell voltage; maximum coin-cell internal resistance; minimum Cbackup; hot/cold device corners | VBackup remains above required backup-domain minimum; no chatter; no excessive transient current
Coin cell → buck handoff | Coin cell initially supplies VBackup | Ramp Vbuck from 0 to nominal | VBackup peak; coin-cell reverse current; source currents; ideal-diode states | Maximum buck voltage; fastest rise; minimum source impedance; device corners | No unacceptable overshoot; no excessive reverse current into coin cell; clean source transfer
Source crossover | Both sources available | Slowly sweep Vbuck through Vcoin in both directions | VBackup; current from each source; partial conduction; diode/FET states | Hot and cold; source-voltage tolerances; worst diode/FET parameters | No chatter; no harmful source sharing; no excessive circulating current
Buck off — reverse leakage | Coin cell powers VBackup; buck rail at 0 V | Hold shutdown state | Current into powered-off buck rail; total coin-cell current | Maximum-temperature leakage; maximum (new or moderately used) coin-cell voltage | Reverse leakage is within battery-life budget and does not materially energize buck rail
Buck on — reverse leakage to coin cell | Buck powers VBackup; coin cell installed | Hold normal operating state | Coin-cell current; ideal-diode leakage; VBackup | Maximum buck voltage; minimum (end of life) coin-cell voltage; hot leakage corner | Coin cell is not charged beyond allowable reverse current; leakage meets battery-life budget
GPIO leakage with VDD = 0 | MCU main VDD off; backup-related nodes energized | Apply normal backup voltage with MCU unpowered | GPIO injection current; dead VDD rail voltage; backup current | Maximum node voltage; hot leakage corner | No absolute-max injection violation; no unintended powering of MCU rail
Backup-capacitance sizing | Buck → coin-cell handoff | Sweep Cbackup starting at 1 µF | Minimum VBackup; capacitor discharge current; droop duration | Minimum capacitance tolerance; DC-bias derating; end-of-life coin cell; maximum backup load | Smallest selected nominal capacitance maintains VBackup above required minimum with margin
Brand-new coin-cell insertion | Cbackup discharged; main power absent | Connect fresh coin cell | Peak battery current; capacitor inrush; VBackup rise | Maximum fresh-cell voltage; minimum cell ESR; maximum Cbackup | Battery and OR-device transient currents remain within ratings
No coin cell installed | Buck operating normally; backup source open | Power buck on/off | VBackup waveform; floating nodes; leakage paths | Minimum Cbackup; maximum backup load | Normal operation unaffected; shutdown is deterministic; no unsafe floating state
Reversed coin cell | Main power both on and off | Reverse battery polarity | Reverse current; device voltages; VBackup | Maximum battery voltage; minimum path resistance | No destructive current or overstress; reverse polarity does not damage OR network
Backup node short | One or both sources present | Short VBackup to ground | Buck current; coin-cell current; OR-device current/dissipation | Maximum source voltage; minimum source resistance | No device exceeds ratings or creates unsafe battery current
Buck rail short | Coin cell installed and backup active | Short buck/main rail to ground | Coin-cell backfeed current; VBackup; OR-device current | Maximum coin-cell voltage; worst reverse-isolation corner | Coin cell does not materially feed the faulted buck rail; current remains safe
2 V buck / partial-power condition | Coin cell installed; buck rail stuck near intermediate voltage | Hold Vbuck at 2 V, optionally sweep around it | VBackup; source currents; diode/FET states; GPIO/main-rail leakage | Hot/cold; source tolerance combinations | No chatter, abnormal source sharing, or unintended partial powering
Hot-temperature corner | Relevant steady-state and crossover conditions | Set models to maximum relevant temperature | Reverse leakage; FET conduction loss; source currents | Maximum specified operating temperature | Leakage and device dissipation remain within budget/ratings
Cold-temperature corner | Relevant handoff/crossover conditions | Set models to minimum relevant temperature | FET behavior; handoff voltage; coin-cell droop/current | Minimum specified operating temperature; high cell resistance | Handoff still succeeds; VBackup remains valid
Buck startup / overshoot | Coin cell present or absent | Apply worst-case buck startup waveform | Peak VBackup; capacitor current; coin-cell reverse current | Maximum buck voltage; fastest rise; minimum load | VBackup remains below absolute maximum; reverse current acceptable
Buck-side ideal diode shorted | Coin cell and buck present | Short buck-side ideal-diode element | Source-to-source current; coin-cell current; rail voltages | Maximum buck/coin-cell voltage difference; minimum source impedance | No unsafe coin-cell charge current or destructive source contention
Coin-cell-side ideal diode shorted | Coin cell and buck present | Short battery-side ideal-diode element | Coin-cell charge current; source currents; VBackup | Maximum buck voltage; minimum cell voltage | No unsafe charging or destructive current
Both ideal diodes shorted | Both sources installed | Short both OR elements | Direct source-to-source current; rail voltages; dissipation | Maximum source-voltage differential; minimum source impedance | Either current remains inherently safe or condition is identified as an unacceptable fault mode requiring mitigation

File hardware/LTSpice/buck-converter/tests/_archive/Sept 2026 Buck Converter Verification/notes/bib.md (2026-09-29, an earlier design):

# Buck Convertor Design Bibliography

## First Principles

Basic theory of operation: 
- https://www.allaboutcircuits.com/technical-articles/understanding-switch-mode-regulation-the-buck-converter/

Equations for non-isolated circuit in continuous-conduction mode: 
- Art of Electronics, 3rd Edition, by Paul Horowitz and Winfield Hill, 9.6.5 Step-down (buck) converter (pg. 644). 

## Major Datasheets

LT-8640A:
- https://www.analog.com/media/en/technical-documentation/data-sheets/lt8640a.pdf
    - Pg. 12 - Block Diagram
    - Pg. 14-22 - Applications Information
    - Pg. 23 - Relevant Typical Application (3.3V, 5A Step-Down Converter)

## Design Notes

1. See bib.ods for a full list of sources and parameters found on each source.
2. A reference circuit from the LT-8640A datasheet was used for the buck convertor design.
3. Minimum component tolerance factors are calculated with this formula: 1-Tol. %

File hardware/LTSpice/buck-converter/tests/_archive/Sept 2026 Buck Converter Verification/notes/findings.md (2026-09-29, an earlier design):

# Buck Converter LTSpice Simulation Findings
## 1. VIN bulk smoothing capacitor
### Design Criteria
1. Exceed the minimum buck converter input voltage of 3.4VDC at worst-case battery voltage to maintain 3.3 V regulation at worst-case load.
    - 3.4V is needed to achieve 3.3V VOUT minimum according to VIN step testing using baseline model.
2. Output voltage ripple shall remain at or below 5% peak-to-peak of the nominal 3.3 V DC rail (0.165 VPP). Ripple shall be evaluated separately and verified not to compromise downstream device operation.
3. RMS/ripple current and peak voltage must remain within selected capacitor's ratings.
    - Each test will have two cases:
        High V_{OC}, Moderate R_{INT} - Corresponding to a new battery, and exposing 
        Moderate V_{OC}, High R_{INT} - Corresponding to a used battery with minimum internal resistance
        Low V_{OC}, High R_{INT} - Corresponding to and old battery
4. Input-capacitor charging shall not produce excessive battery voltage sag or sustained high-current loading during any transition (startup and playback in this case).
5. The volumetrically smallest capacitor that meets these requirements is desirable.

### Tests

Three tests will be run to answer the above questions and to determine a part to use for the input bulk capacitor. The tests and their purposes are as follows:

1. Startup
    - Determines worst-case initial currents and voltages, which informs:
        - Input Bulk capacitor current stress
        - Battery stress
        - Regulator startup time
        - Switching inductor current stress
    - Measurements:
        - Peak inrush current at battery and input bulk capacitor.
            A/B. new battery
            C/D. moderately used battery
        - Peak switching inductor current
            E. new battery
            F. moderately used battery
        - G. time for VIN to reach 3.4 V (buck regulation threshold), old battery
2. Steady-State
    - Determines input/output voltage regulation and ripple during steady-state playback, which affects:
        - Microcontroller / amplifier stability
        - Continuous component stress
    - Measurements:
        - A. Vin Average, old battery
        - B. Vin PP voltages, old battery
        - C. Peak Switching inductor current, new battery
        - D. Input capacitor RMS current, new battery
3. Idle to Playback at 80% volume
    - Informs:
        - Input Bulk capacitor current stress
        - Battery stress
        - Regulator/load-step recovery time
        - Switching inductor current stress
    - Measurements:
        - Peak transient current at battery and input capacitor
            A/B. new
            C/D. moderately used battery
        - Load-step peak (min) transient current magnitude and recovery time to loaded steady state at battery and input bulk capacitor
            E/F. new
            G/H. moderately used battery
        - I. Load-step peak (min) [voltage sag, recovery time to loaded steady state] (brackets), at battery, old battery
        - Peak switching inductor current
            J. new battery
            K. moderately used battery

Input capacitor stress:
- 1B, 1D, 2D, 3B, 3D

Based on the tabulated results in findings.ods, steady-state input ripple is the only improvement significant enough to drive the capacitor selection. Based on those results, a 10uF capacitor is chosen due to diminishing returns beyond that value, as a 47 uF capacitor will have only about 12mVPP lower than a 10uF capacitor and will also have an increased startup delay, with 5.76 ms at 10 µF versus 24.2 ms at 47 µF. Additionally, larger capacitances will generally require larger components.

The maximum current seen at the switching inductor of 2.44A is observed in the transition from idle to playback. This is well below the saturation current listed in the datasheet of 7.4A and is deemed acceptable.

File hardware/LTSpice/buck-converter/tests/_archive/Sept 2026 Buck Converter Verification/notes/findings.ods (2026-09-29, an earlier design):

 | Capacitor | 100nF | 4.7uF | 10uF | 22uF | 47uF | Unit
Test
SU-A |  | 8.29 | 9.52 | 9.97 | 10.38 | 10.66 | A
SU-B |  | 0.791 | 6.33 | 8.07 | 9.37 | 10.15 | A
SU-C |  | 10.31 | 12.89 | 14.01 | 15.12 | 15.97 | A
SU-D |  | 0.791 | 8.57 | 11.33 | 13.65 | 15.21 | A
SU-E |  | 0.693 | 0.694 | 0.694 | 0.694 | 0.694 | A
SU-F |  | 0.693 | 0.692 | 0.692 | 0.693 | 0.693 | A
SU-G |  | 0.993 | 3.1 | 5.76 | 11.8 | 24.2 | ms
SS-A |  | 3.61 | 3.61 | 3.61 | 3.61 | 3.61 | V
SS-B |  | 65 | 28 | 20 | 14 | 8 | mV
SS-C |  | 0.912 | 0.913 | 0.913 | 0.913 | 0.913 | A
SS-D |  | 0.0325 | 0.246 | 0.292 | 0.321 | 0.336 | A_RMS
LP-A |  | 3.25 | 2.82 | 2.45 | 2.09 | 1.7 | A
LP-B |  | 3.16 | 1.84 | 1.8 | 2.08 | 2.65 | A
LP-C |  | 3.25 | 3.02 | 3.04 | 2.78 | 2.39 | A
LP-D |  | 3.03 | 1.48 | 1.41 | 1.71 | 2.21 | A
LP-E |  | 68.3 | 69.4 | 70.4 | 80.3 | 104 | us
LP-F |  | 1.91 | 4.17 | 4.06 | 3.79 | 4.26 | us
LP-G |  | 63.2 | 66.6 | 68.7 | 72.8 | 81.2 | us
LP-H |  | 0.23 | 4.5 | 0.476 | 4.73 | 4.7 | us
LP-I |  | [3.24, 43.6] | [3.19, 74.5] | [3.17, 85.3] | [3.19, 84.8] | [3.22, 55.9] | [V, us]
LP-J |  | 3.39 | 3.27 | 3.16 | 3.05 | 3.29 | A
LP-K |  | 3.3 | 3.24 | 3.33 | 3.35 | 3.36 | A

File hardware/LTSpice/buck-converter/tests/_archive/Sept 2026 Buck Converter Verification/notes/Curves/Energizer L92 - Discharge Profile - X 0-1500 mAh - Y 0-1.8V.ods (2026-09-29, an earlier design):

 | Pixels | Units
X | 650 | 1500
Y | 15 | 1.8
Origin | 18
 | 255
 | X-Pix | Y-Pix | mAh Used | Volts
 | 19 | 92 | 2 | 1.22
 | 120 | 97 | 242 | 1.19
 | 229 | 104 | 501 | 1.13
 | 323 | 110 | 724 | 1.09
 | 433 | 121 | 985 | 1.01
 | 495 | 131 | 1132 | 0.93
 | 510 | 135 | 1168 | 0.90
 | 525 | 141 | 1203 | 0.86
 | 538 | 149 | 1234 | 0.80
 | 548 | 161 | 1258 | 0.71
 | 553 | 176 | 1270 | 0.59
 | 556 | 191 | 1277 | 0.48
 | 559 | 254 | 1284 | 0.01

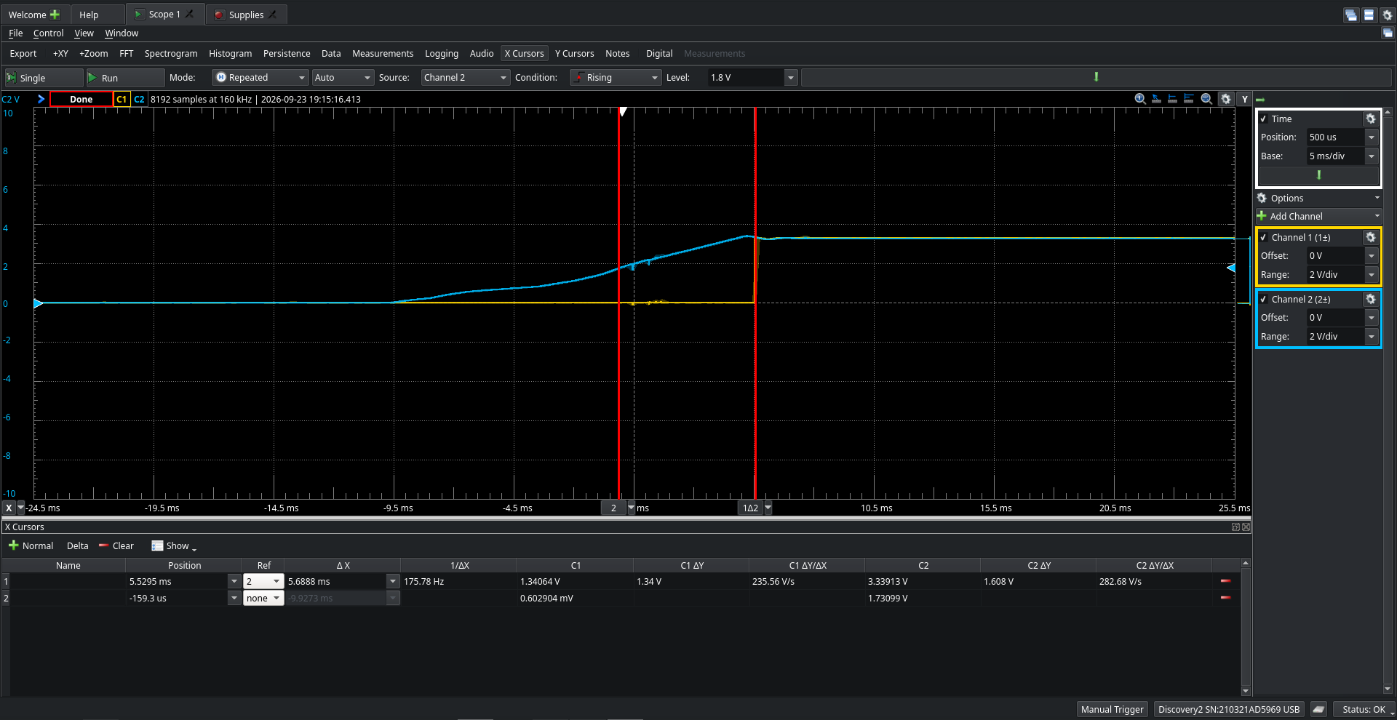
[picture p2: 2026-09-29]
experiments/gpio-assert-test/Captures/GPIO Assert Delay.png

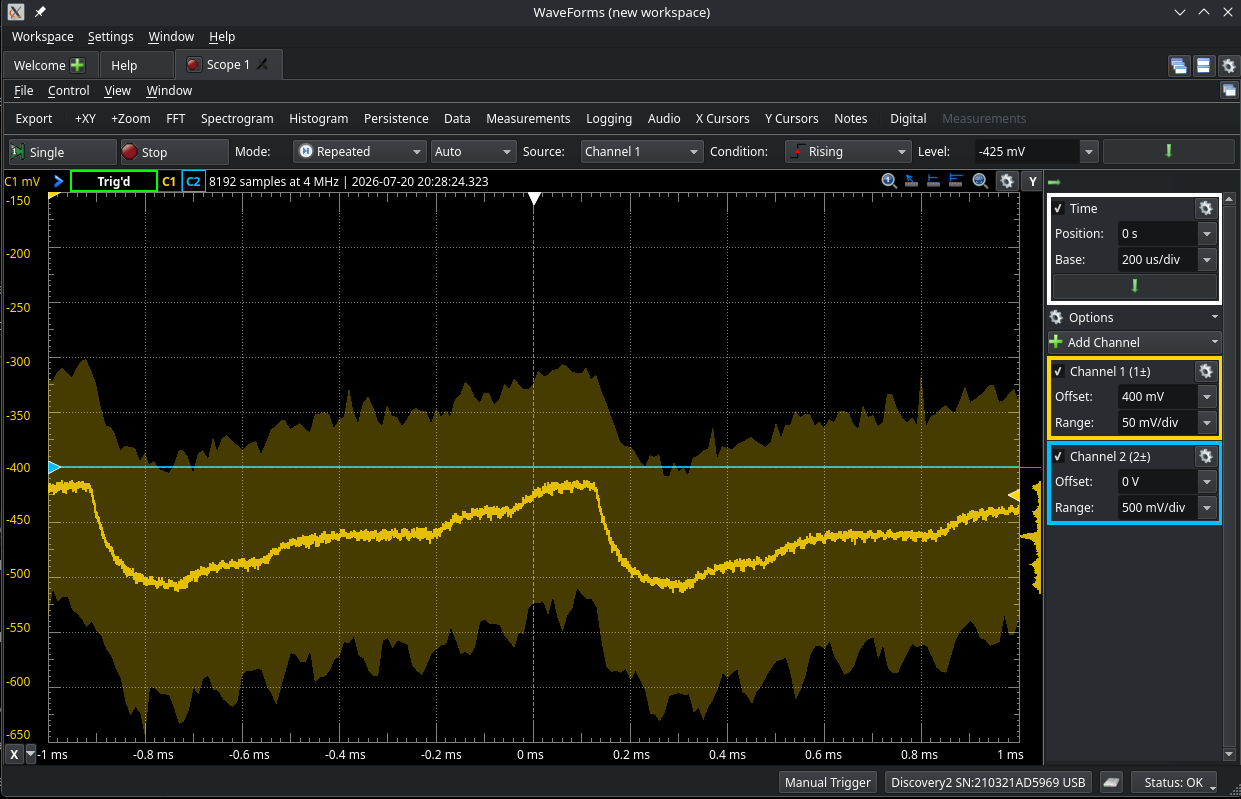
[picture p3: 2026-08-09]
experiments/audio-test/Captures/7-20-2026/Sawtooth-Low-Variance.png

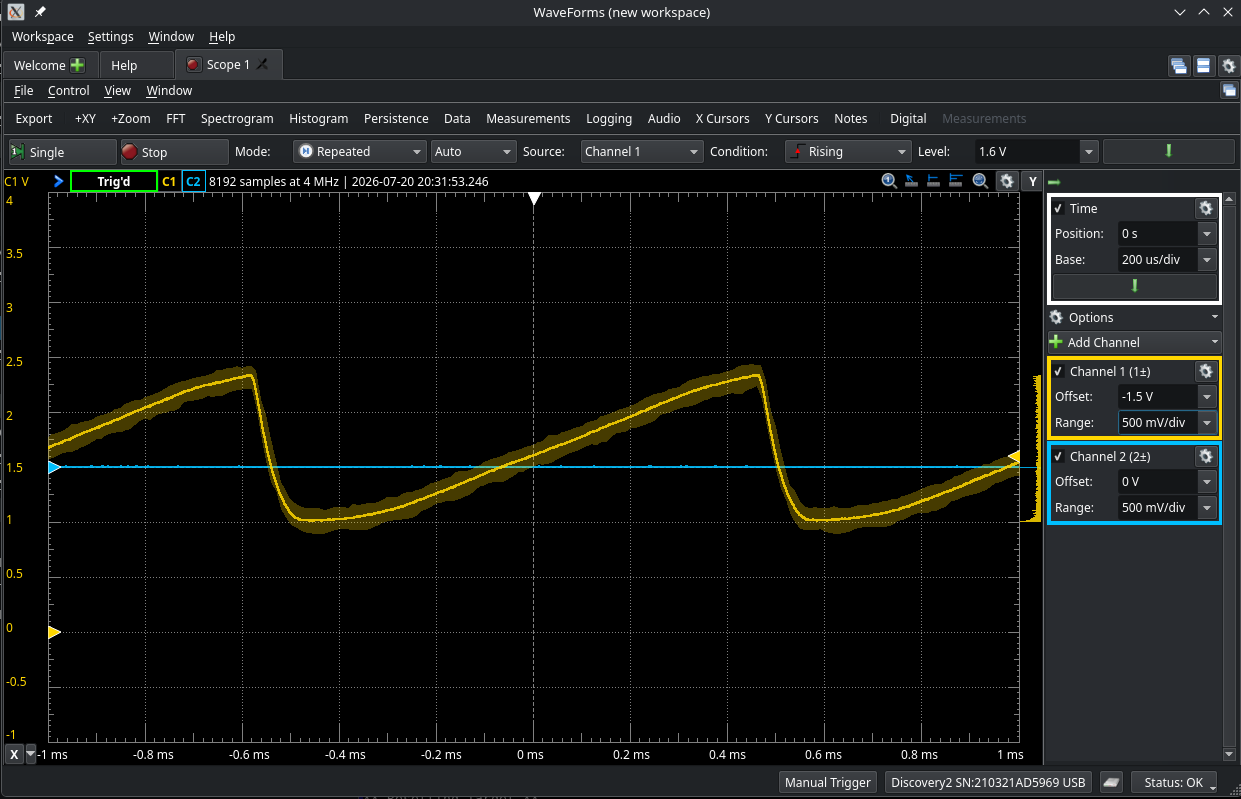
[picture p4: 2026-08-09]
experiments/audio-test/Captures/7-20-2026/Final-Sawtooth.png

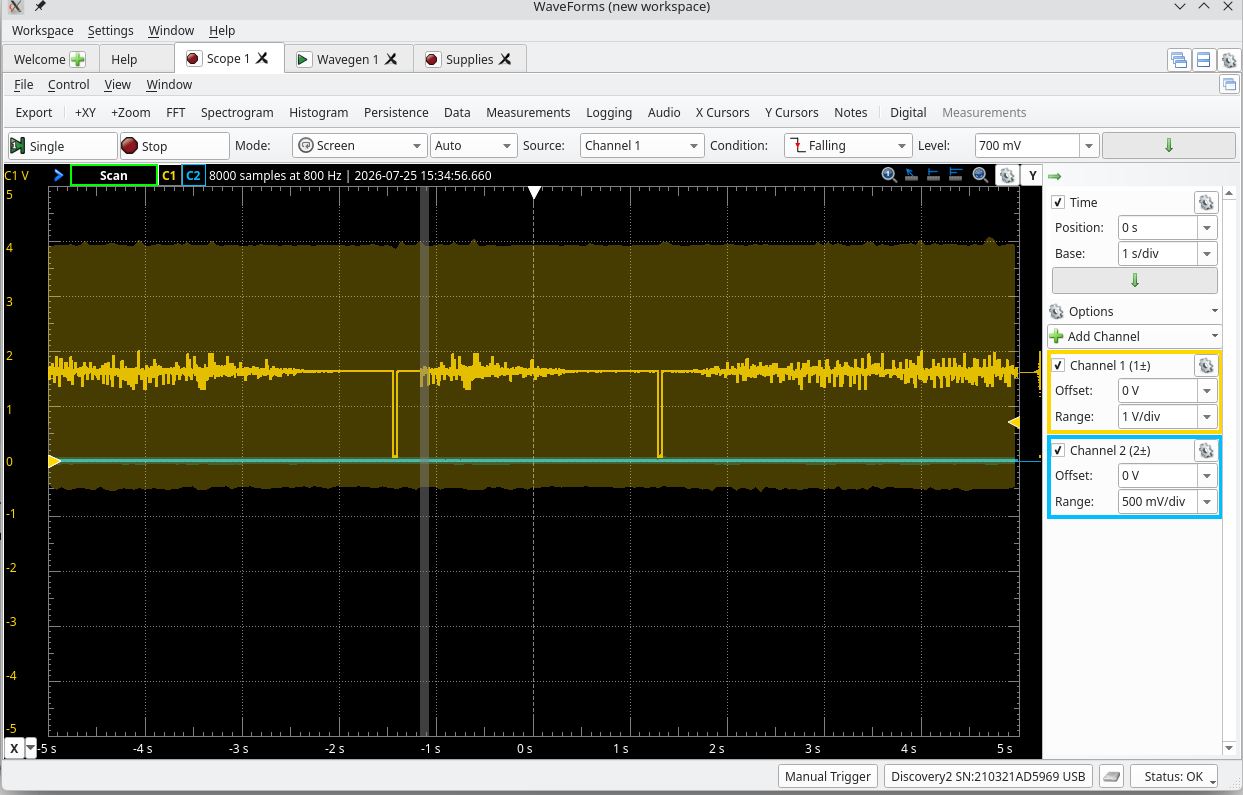
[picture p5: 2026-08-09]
experiments/audio-test/Captures/7-25-2026/Elephant_filtered_unamplfied.png

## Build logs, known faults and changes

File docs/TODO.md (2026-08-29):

# Restarting the project

[x] Write a TODO
[x] Write a Readme - 3 hr
[x] Look over all files - 1.5 hr
[x] Compile the project in some form and run it on a dev board - 3 hr

# Audio playback

[x] Write audio player code - 20 hr
[x] Write ADPCM code - 15 hr

# Tilt Switch Verification
[ ] Design tests for tilt switch circuit - 1 hr
[ ] Breadboard tilt switch circuit - 0.5 hr
[ ] Verify circuit meets specified requirements - 1 hr

# Eval Board 
### (Note 1)

[ ] Engineering checks on all subcircuit schematics - 24 hr
[ ] Board Layout - 10 hr
[ ] Create BOM - 3 hr
[ ] Order PCB - 0.5 hr
[ ] Order parts - 0.5 hr
[ ] Resistance checks before power - 0.5 hr
[ ] Power board without speaker; verify rails and amp config - 1 hr
[ ] Verify I2S clocks on board - 1 hr
[ ] Play test tone through speaker - 1 hr
[ ] Play real elephant audio sample - 1 hr

# Target Firmware
### (Note 1)
[ ] Write I2S code - 2 hr
[ ] Write EEPROM code - 2 hr
[ ] Write main state machine code - 12 hr
[ ] implement playback cooldown using RTC - 6 hr
[ ] Determine sleep management functionality - 3 hr
[ ] Write sleep management code - 6 hr

# Power/Sleep Management Measurements
[ ] Measure SSM, EEPROM, and black pill currents across the target states and at desired volume - 3 hr
[ ] Re-evaluate power requirements based on measurements - 2 hr
[ ] Modify circuit schematics according to conclusions - 2 hr

# Final PCB
[ ] Adjust schematics based on eval board notes - 5 hr
[ ] Layout final PCB - 15 hr
[ ] Verify PCB - 2 hr
[ ] Check audio routing: MCLK/BCLK/LRCLK/DATA short, clean, referenced to ground - 0.5 hr
[ ] Check amplifier output / speaker current / thermal assumptions - 0.5 hr
[ ] Create BOM, choosing up-to-date parts - 3 hr
[ ] Order PCB - 0.5 hr
[ ] Order parts - 0.5 hr

# Bring-up
[ ] Resistance checks before power - 0.5 hr
[ ] Power board without speaker; verify rails and amp config - 1 hr
[ ] Verify I2S clocks on board - 1 hr
[ ] Play test tone through speaker - 1 hr
[ ] Play real elephant audio sample - 1 hr
[ ] Verify shutdown / wakeup path - 3 hr
[ ] Note fixes needed for main board - 1 hr

# Finishing up project
[ ] Run tests and verify functionality of board - 6 hr
[ ] Enclosure design - 3 hr
[ ] Final integration - 2 hr
[ ] Tie documentation up into a neat bow - 3 hr
[ ] The end.

# Notes
1. Target firmware and eval-board hardware work may proceed in parallel.

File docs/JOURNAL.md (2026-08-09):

### Parking Lot
- 4-layer board for noise and component placement
- Give the board to someone for review
- Backing up data between shutdowns using backup domain
- Code is a mess
- Test the buck converter circuit with components i already have to see if it would basically work in the real world as-designed (check if I changed it substantially since I got boards)
- Replace flip flop with momentary buck enable circuit to allow the MCU to self-latch the buck enable pin.
    OPEN QUESTION
    How long must the buck enable pulse be to guarantee MCU self-latch?
    OPEN QUESTION
    Can a passive RC + diode OR buck-enable circuit reliably hold EN long enough for MCU self-latch without unacceptable standby current? Prefer passive RC solution unless testing/simulation shows unreliable wake capture. Reject active assist circuitry unless its standby current is acceptably low.
    OPEN QUESTION
    How long does the abnormal switch condition last and is it enough to charge the capacitor?
    TEST PLAN
    Capture real tilt-switch waveform (including bounce and event duration), apply it to the candidate RC + diode EN circuit at worst-case coin-cell voltage, and measure EN peak voltage plus time above 1 V to determine whether passive wake capture is reliable.

### Log
2/1/2026 - Put together a TODO. Looking over files and README is next.
2/3/2026 
    - Started README.md.
    - Looked at all major components
    - Concerns about D-flip flop - Why did I choose to do this and what does it do in the circuit exactly?
    - Considered battery calculations
    - Considered state machine
    - Considered buck converter design choices
2/7/2026
    - Revised tilt switch / flip flop function: tilt switch turns buck on, MCU turns buck off.
    - Revised KICAD schematic to reflect above changes
    - Created a power condition table
    - Determined that BAT54 is good enough
        - 2uA backcurrent will not catastrophically fail CR2032
        - use of buck converter for power will not exceed 4 hours at a time, usually followed by a day or more of being on coin cell power
        - Therefore, the effect on the coin cell is acceptable.
2/10/2026
    - Resolved to use LM66100 instead of BAT54 for power switching
    - Added decoupling caps to flip flop
2/14/2026
    - Buck converter simulations done
    - Started working on LM66100 simulations
    - Modified schematic to use LM66100
2/15-3/1/2026 or so
    - Completed LM66100 model that works and mostly approximates electrical properties
3/7/2026
STATE:Simulation
    - Re-simulated buck converter in LTSpice with 4x L92 AAA batteries instead. Tested 3 different voltages and 4 different internal resistances. The batteries will not affect performance during the reasonable life of the batteries.
    - Began modelling power source OR circuit in LTSpice
        Goal: verify no harmful back-current into coin cell
    - Began modelling buck enable trigger circuit in LTSpice
        Goal: verify behaviour
CURRENT TARGET
Validate power source OR circuit behavior before modifying buck enable architecture

NEXT STEPS
1. Test OR circuit: 3 different voltages for each source
2. Measure backup voltage
3. Measure back-current to coin cell

THEN
- Finish buck enable trigger circuit
- Put D-flip flop in its own subckt (or replace)
- Test buck enable trigger circuit with emulated logic pin

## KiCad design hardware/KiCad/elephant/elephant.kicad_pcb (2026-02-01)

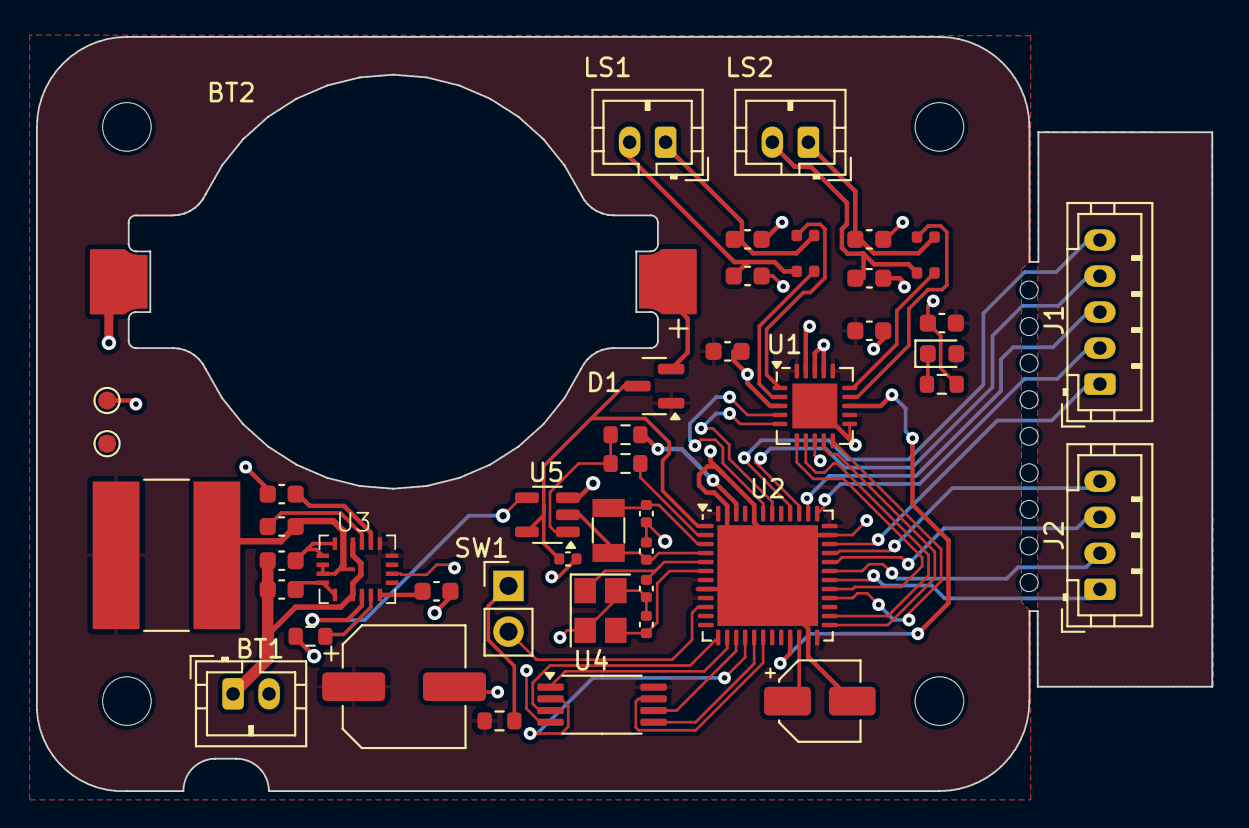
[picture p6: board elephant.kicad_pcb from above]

Board: 2 copper layers, 65.3 x 41.9 mm, 51 parts (0 on the bottom side), 54 nets.

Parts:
BT1: 9v Battery; JST_PH_B2B-PH-K_1x02_P2.00mm_Vertical
BT2: Coin Cell; BatteryHolder_Keystone_1057_1x2032
C1, C2, C3, C4: 470pF; C_0603_1608Metric
C5, C7: 100nF; C_0603_1608Metric
C6: 4.7uF; C_0603_1608Metric
C8: 10nF; C_0603_1608Metric
C9, C11, C13, C14: 1uF; C_0603_1608Metric
C10, C12: 4.3pF; C_0402_1005Metric
C15, C16: 12pF; C_0402_1005Metric
C17: 100u; CP_Elec_6.3x5.3
C18: 100nF; C_0402_1005Metric
C19: 4.7uF,<1Ω; CP_Elec_4x5.4
D1: BAT54C; SOT-23
D2: LED; LED_0603_1608Metric
FB1, FB2, FB3, FB4: FerriteBead_Small; L_0402_1005Metric
H1, H2, H3, H4: MountingHole; MountingHole_2.7mm_M2.5
J1: Conn_01x05_Pin; JST_PH_B5B-PH-K_1x05_P2.00mm_Vertical
J2: Conn_01x04_Pin; JST_PH_B4B-PH-K_1x04_P2.00mm_Vertical
L1: 2.2uH; L_Bourns-SRN8040_8x8.15mm
LS1, LS2: Speaker; JST_PH_B2B-PH-K_1x02_P2.00mm_Vertical
R1, R4, R5: 10k; R_0603_1608Metric
R2: 17.8k; R_0603_1608Metric
R3: 330 Ω; R_0603_1608Metric
SW1: SW_TILT; PinHeader_1x02_P2.54mm_Vertical
TP1: GND; TestPoint_Pad_D1.0mm
TP2: 3v3; TestPoint_Pad_D1.0mm
U1: SSM2518; QFN-20-1EP_4x4mm_P0.5mm_EP2.5x2.5mm
U2: STM32F401CCUx; QFN-48-1EP_7x7mm_P0.5mm_EP5.6x5.6mm
U3: LT8640
U4: M95M04; TSSOP-8_4.4x3mm_P0.65mm
U5: 74AUP1G79; SOT-23-5
Y1: 32.768kHz, 6pF, 50kΩ; Crystal_SMD_3215-2Pin_3.2x1.5mm
Y2: 25MHz, 9pF; Crystal_SMD_3225-4Pin_3.2x2.5mm

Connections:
+3.3V: C5.1, C6.1, C7.1, C17.1, D1.1, D2.2 (A), L1.2, R1.1, TP2.1, U1.12 (DVDD), U1.16 (PVDD), U1.20 (PVDD), U2.7 (NRST), U2.9 (VREF+), U2.24 (VDD), U2.36 (VDD), U2.48 (VDD), U3.1 (Bias), U3.20 (Vout), U4.8 (VCC)
+9V: BT1.1 (+), C11.2, C14.1, U3.4 (Vin1), U3.13 (Vin2)
+BATT: C18.1, D1.3, U2.1 (VBAT), U5.5 (VCC)
/I2C_SCL: U1.5 (SCL), U2.42 (PB6)
/I2C_SDA: U1.4 (SDA), U2.43 (PB7)
/I2S_bit_clock: U1.7 (BCLK), U2.26 (PB13)
/I2S_data: U1.10 (SDATA), U2.28 (PB15)
/I2S_master_clock: U1.6 (MCLK), U2.29 (PA8)
/I2S_word_clock: U1.9 (LRCLK), U2.25 (PB12)
/Power/buck_en: U3.14 (EN/UV), U5.4 (Q)
/Power/pwr_buck_toggle: R4.2, R5.2, U5.1 (D)
/hold_eeprom: U2.18 (PB0), U4.7 (~HOLD)
/jtck_swclk: J1.2, U2.37 (PA14)
/jtdi: J1.3, U2.38 (PA15)
/jtdo-swo: J1.4, U2.39 (PB3)
/jtms_swdio: J1.1, U2.34 (PA13)
/jtrst: J1.5, U2.40 (PB4)
/osc32_in: C10.2, U2.3 (PC14), Y1.1
/osc32_out: C12.2, U2.4 (PC15), U5.2 (C), Y1.2
/osc_in: C15.2, U2.5 (PH0), Y2.1
/osc_out: C16.2, U2.6 (PH1), Y2.3
/pwr_aud: U1.13 (SD), U2.21 (PB10)
/pwr_buck_off: R5.1, U2.46 (PB9)
/pwr_buck_on: R4.1, U2.2 (PC13)
/pwr_eeprom: U2.14 (PA4), U4.1 (~S)
/spi1_miso: U2.16 (PA6), U4.2 (Q)
/spi1_mosi: U2.17 (PA7), U4.5 (D)
/spi1_sck: U2.15 (PA5), U4.6 (C)
/sw_tilt: SW1.2 (B), U2.10 (PA0)
/uart_cts: J2.3, U2.32 (PA11)
/uart_rts: J2.4, U2.33 (PA12)
/uart_rx: J2.2, U2.31 (PA10)
/uart_tx: J2.1, U2.30 (PA9)
/write_eeprom: U2.13 (PA3), U4.3 (~W)
GND: BT1.2 (-), BT2.2 (-), C1.2, C2.2, C3.2, C4.2, C5.2, C6.2, C7.2, C8.2, C9.2, C10.1, C12.1, C15.1, C16.1, C17.2, C18.2, C19.2, R2.2, R3.2, TP1.1, U1.3 (ADDR), U1.8 (GND), U1.11 (SAMOD), U1.17 (GND), U1.18 (GND), U1.19 (GND), U1.21 (GND), U2.8 (VSSA), U2.23 (VSS), U2.35 (VSS), U2.44 (BOOT0), U2.47 (VSS), U2.49 (VSS), U3.18 (GND), U4.4 (VSS), U5.3 (GND), Y2.2, Y2.4
unnamed: BT2.1 (+), D1.2
unnamed: C1.1, FB1.2, LS1.1
unnamed: C2.1, FB2.2, LS2.1
unnamed: C3.1, FB3.1, LS1.2
unnamed: C4.1, FB4.1, LS2.2
unnamed: C11.1, U3.6 (GND1), U3.7 (GND1)
unnamed: C13.2, L1.1, U3.8 (SW), U3.9 (SW), U3.21 (SW), U3.22 (SW)
unnamed: C14.2, U3.10 (GND2), U3.11 (GND2)
unnamed: D2.1 (K), R3.1
unnamed: R1.2, SW1.1 (A)
unnamed: FB1.1, U1.1 (OUTL+)
unnamed: FB3.2, U1.2 (OUTL-)
unnamed: FB2.1, U1.14 (OUTR+)
unnamed: FB4.2, U1.15 (OUTR-)
unnamed: C19.1, U2.22 (VCAP1)
unnamed: C13.1, U3.3 (BST)
unnamed: C9.1, U3.2 (INTVcc)
unnamed: R2.1, U3.15 (RT)
unnamed: C8.1, U3.16 (TR/SS)

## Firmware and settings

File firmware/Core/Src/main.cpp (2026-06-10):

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
/* Includes ------------------------------------------------------------------*/

#include "main.h"


/* USER CODE BEGIN Includes */
//#include "audio_test.h"
//#include "sleep_test.h"
//#include "reset_test.h"
/* USER CODE END Includes */

/* USER CODE BEGIN PD */
const int n_interrupts = 2;

const int spi_txcplt_irqn = 0;
const int alarm_wakeup_irqn = 1;
const int gpio_wakeup_irqn = 1;
/* USER CODE END PD */

I2C_HandleTypeDef hi2c1;

I2S_HandleTypeDef hi2s2;
DMA_HandleTypeDef hdma_spi2_tx;

RTC_HandleTypeDef hrtc;

SPI_HandleTypeDef hspi1;

UART_HandleTypeDef huart1;

/* USER CODE BEGIN PV */

//i2sObject i2sObj(hi2s2);
//rtcObject rtcObj(hrtc);
//gpioObject gpioObj(GPIOA);

//InterruptHandler* Handlers[n_interrupts];

//resetCause latestResetCause;

/* USER CODE END PV */

void SystemClock_Config(void);
static void MX_GPIO_Init(void);
static void MX_DMA_Init(void);
static void MX_I2C1_Init(void);
static void MX_I2S2_Init(void);
static void MX_SPI1_Init(void);
static void MX_USART1_UART_Init(void);
static void MX_RTC_Init(void);
//void register_handler(int irq_n, InterruptHandler* handler);
/**
  * @brief  The application entry point.
  * @retval int
  */

int main(void)
{
  HAL_Init();
  MX_GPIO_Init();

  while (1)
  {
    HAL_GPIO_TogglePin(ld_heartbeat_GPIO_Port, ld_heartbeat_Pin);
    HAL_Delay(500);
  }
}

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
/* USER CODE BEGIN 4 */

extern "C" void HAL_I2S_TxCpltCallback(I2S_HandleTypeDef *hi2s) {
  //Handlers[spi_txcplt_irqn]->irq();
}                      

extern "C" void HAL_GPIO_EXTI_Callback(uint16_t GPIO_Pin) {
}

//void register_handler(int irq_n, InterruptHandler* handler) {
    //Handlers[irq_n] = handler;
//}

/* USER CODE END 4 */
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


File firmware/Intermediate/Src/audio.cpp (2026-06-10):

#include "audio.h"


Audio::Audio(I2C_HandleTypeDef& hi2c, DMA_HandleTypeDef& hdma_spi_tx, i2sObject& i2sObj) :
            hi2c(&hi2c), hdma_spi_tx(&hdma_spi_tx), i2sObj(&i2sObj)
            {}

Audio::Audio() : hi2c(nullptr), hdma_spi_tx(nullptr), i2sObj(nullptr)
            {}

Audio::Audio(const Audio& other) :
            hi2c(other.hi2c), hdma_spi_tx(other.hdma_spi_tx), i2sObj(other.i2sObj)
            {}

Audio& Audio::operator=(const Audio& other) {
    this->hi2c = other.hi2c;
    this->hdma_spi_tx = other.hdma_spi_tx;
    this->i2sObj = other.i2sObj;
    return *this;
}

void Audio::play() {
    while (i2sObj->getResource().State != HAL_I2S_STATE_READY) {}
	if (HAL_I2S_Transmit_DMA(&i2sObj->getResource(), (uint16_t*) sampleBuffer.data(),
        (uint16_t) sampleBuffer.size()) != HAL_OK) {
            Error_Handler();
        }
    i2sObj->resetFlag();
}

std::array<int16_t,audio_buffer_size*nSpeakers()>& Audio::getBufferInstance() {
    return sampleBuffer;
}

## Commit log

2026-02-01 Created TODO, JOURNAL
    [ElephantR7.csv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]
2026-05-31 Added KiCad project files, LTSpice files, and documentation files.
    [ElephantR7.csv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]
2026-06-06 Restore manual STM32 build flash debug workflow
2026-06-10 Reading SD Card
    SD card to be used for temporary storage for audio-test
    [ElephantR7.csv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]
2026-06-28 Audio player software design started.
    [Elephant0.9.2-B_Cu.gbr, Elephant0.9.2-B_Mask.gbr, Elephant0.9.2-B_Paste.gbr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]
2026-07-04 Spooler silence-filling, fake sink and storage.
    [elephant.csv, elephant.kicad_pcb, elephant.kicad_sch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]
2026-07-16 AudioPlayer happy path, error handling, and underrun behavior are tested and work in fake environment.
    [audio-test.ioc, pwm_audio_sink.h]
2026-07-25 AudioPlayer, PWMAudioSink, and SdCard work in real environment.
2026-08-09 Implemented ADPCM codec, tested on PC, and refactored AudioPlayer to use a new SampleSource object, to be tested.
2026-08-24 PCMSampleSource tested. Tracing AudioPlayer source_ interface bugs.
    [pwm_audio_sink.h]
2026-08-24 Fixed a stupid bug at AudioPlayer.start where source_.start was called prematurely. Traced another known bug part of the way.
2026-08-29 Planning ahead for evaluation board.
    [elephant.kicad_sch, power.kicad_sch]
2026-09-29 Tilt switch tests completed; tilt switch circuit verified.
    [Energizer L92 - Discharge Profile - X 0-1500 mAh - Y 0-1.8V.ods, Energizer L92 - Internal Resistance Profile - X 0-1600 mAh - Y 0-0.8 Ohms.png.traj.csv, Energi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]

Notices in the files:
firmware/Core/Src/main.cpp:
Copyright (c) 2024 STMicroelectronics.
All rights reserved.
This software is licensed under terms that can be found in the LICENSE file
